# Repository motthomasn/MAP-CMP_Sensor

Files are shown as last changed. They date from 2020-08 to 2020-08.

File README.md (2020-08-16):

# MAP-CMP_Sensor
Small module combining a MAP sensor and engine phase sensor (camshaft posn) for internal combustion engine management

This module was built for my CBR250RRi project. The aim was to allow an aftermarket ECU to achieve 720deg synchronisation or engine phase detection without the use of a physical camshaft position sensor being installed on the engine. It has been designed for use on a port throttled engine and sample the pressure pulses from a single inlet port. 

The board uses an NXP pressure sensor to measure the pressure pulses. The pressure signal is passed to an LM397 comparator and compared to a reference voltage which can be adjusted via trim pot. The output signal from the comparator is normally high but when the pressure signal falls below the reference voltage, the output is pulled low. With the reference voltage set correctly, a reliable "cam position" signal can be achieved consisting of a single pulse per engine cycle.

Note: In a port throttled engine, the pressure signal may not be strong enough to produce a reliable signal throughout the engine speed/load range. In my application this is fine as the ECU I am working with (Life Racing F88R) allows the option to ignore the engine phase signal once 720deg synchronisation has been achieved. This means that the signal only has to be reliable during starting and idle.

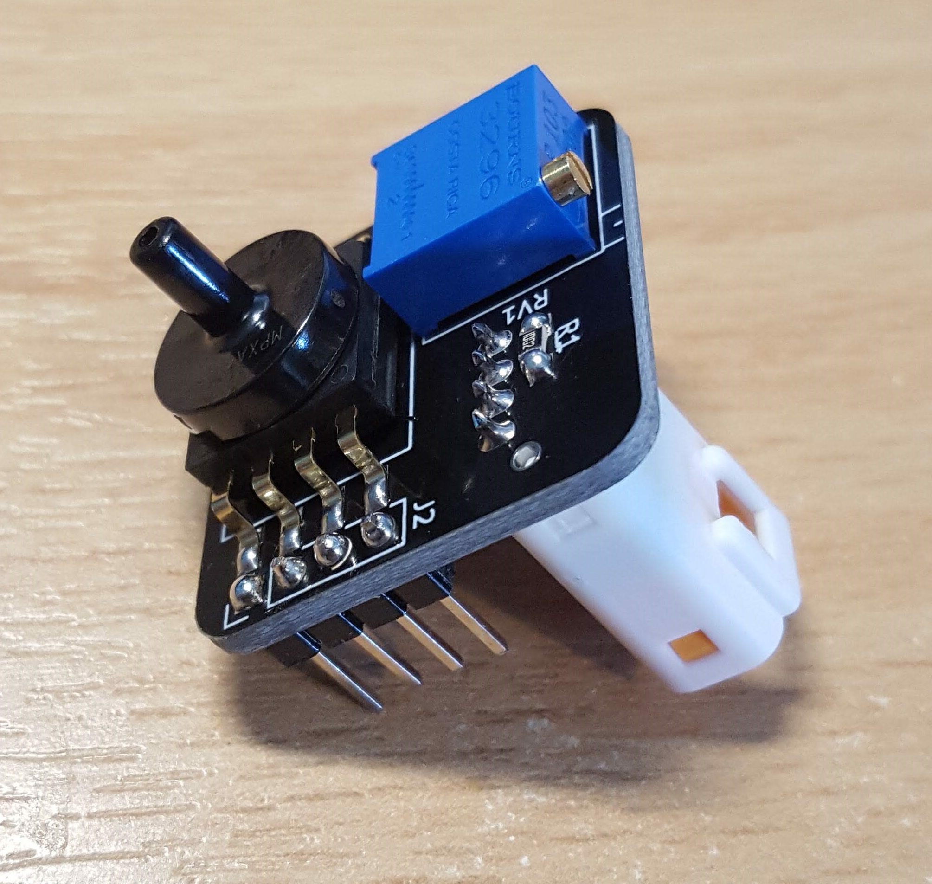
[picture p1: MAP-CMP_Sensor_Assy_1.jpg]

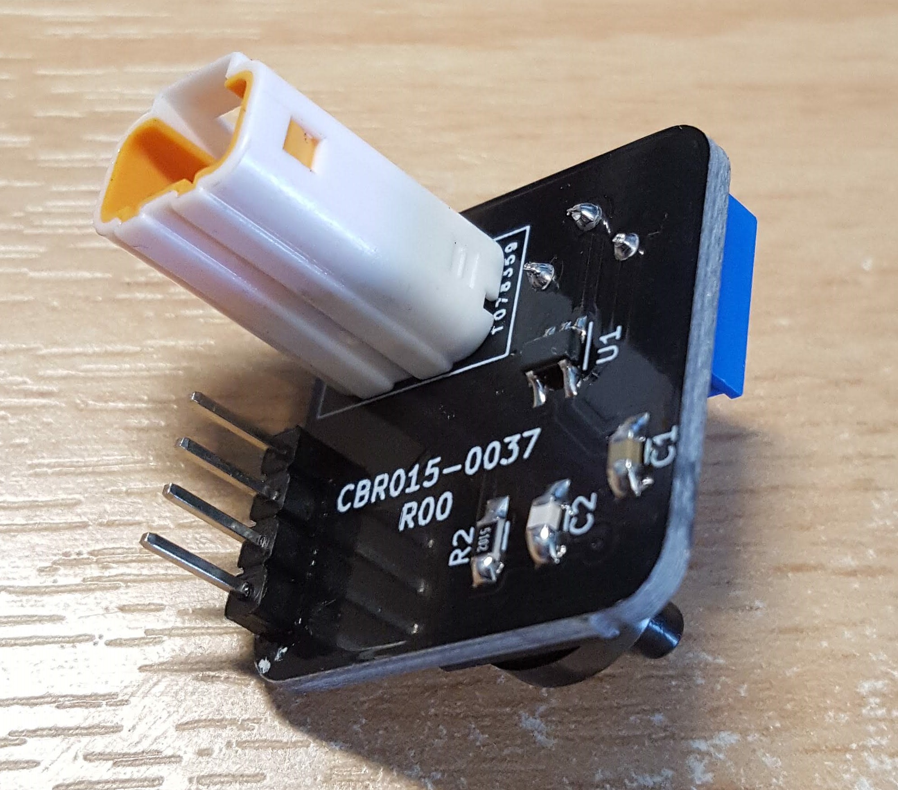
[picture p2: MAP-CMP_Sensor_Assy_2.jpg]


For further details on the CBR250RRi project, refer to the website https://www.cbr250rri.com/.

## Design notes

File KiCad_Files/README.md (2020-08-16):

This folder contains the KiCad files for the MAP-CMP module.

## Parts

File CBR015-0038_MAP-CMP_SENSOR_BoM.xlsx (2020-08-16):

Designation | Description | Value | Manufacturer | Part Number | Package | Supplier | Stock No. / Order Code | Notes | Datasheet
U1 | Comparator | 44μs, 30V | Texas Instruments | LM397MF/NOPB | SOT-23 | RS | 197-7286 |  | https://www.ti.com/lit/ds/symlink/lm397.pdf
U2 | Pressure Sensor | 15-115 kPa | NXP | MPXA6115AC6U |  | RS | 719-1134 |  | https://www.nxp.com/docs/en/data-sheet/MPXA6115A.pdf
RV1 | Trim Pot | 10K | Bourns | 3296P-1-103LF |  | RS | 521-9495 | May be replaced with fixed voltage divider in later revisions | https://www.bourns.com/pdfs/3296.pdf
J1 | Connector | 4 way male | JST | B04B-JWPF-SK-R |  | Farnell | 1324127 |  | http://www.farnell.com/datasheets/2082409.pdf
J2 | Debug Connector | 4 way male |  |  |  | RS |  | Only used to facilitate connection to oscilloscope for initial testing & debug. May be removed in later revisions
C1 | Pressure sensor power smooth cap | 100nF | AVX | 08055C104KAT2A | 0805 | RS | 464-6688
C2 | Pressure sensor output smooth cap | 47pF | KEMET | C0805C470J5GACTU | 0805 | RS | 264-4270
R1 | Comparator output pull-up resistor | 10K | TE Connectivity | CRG0805F10K | 0805 | RS | 223-0562
R2 | Pressure sensor output filter resistor | 51K | Vishay | CRCW080551K0FKEA | 0805 | RS | 679-1525

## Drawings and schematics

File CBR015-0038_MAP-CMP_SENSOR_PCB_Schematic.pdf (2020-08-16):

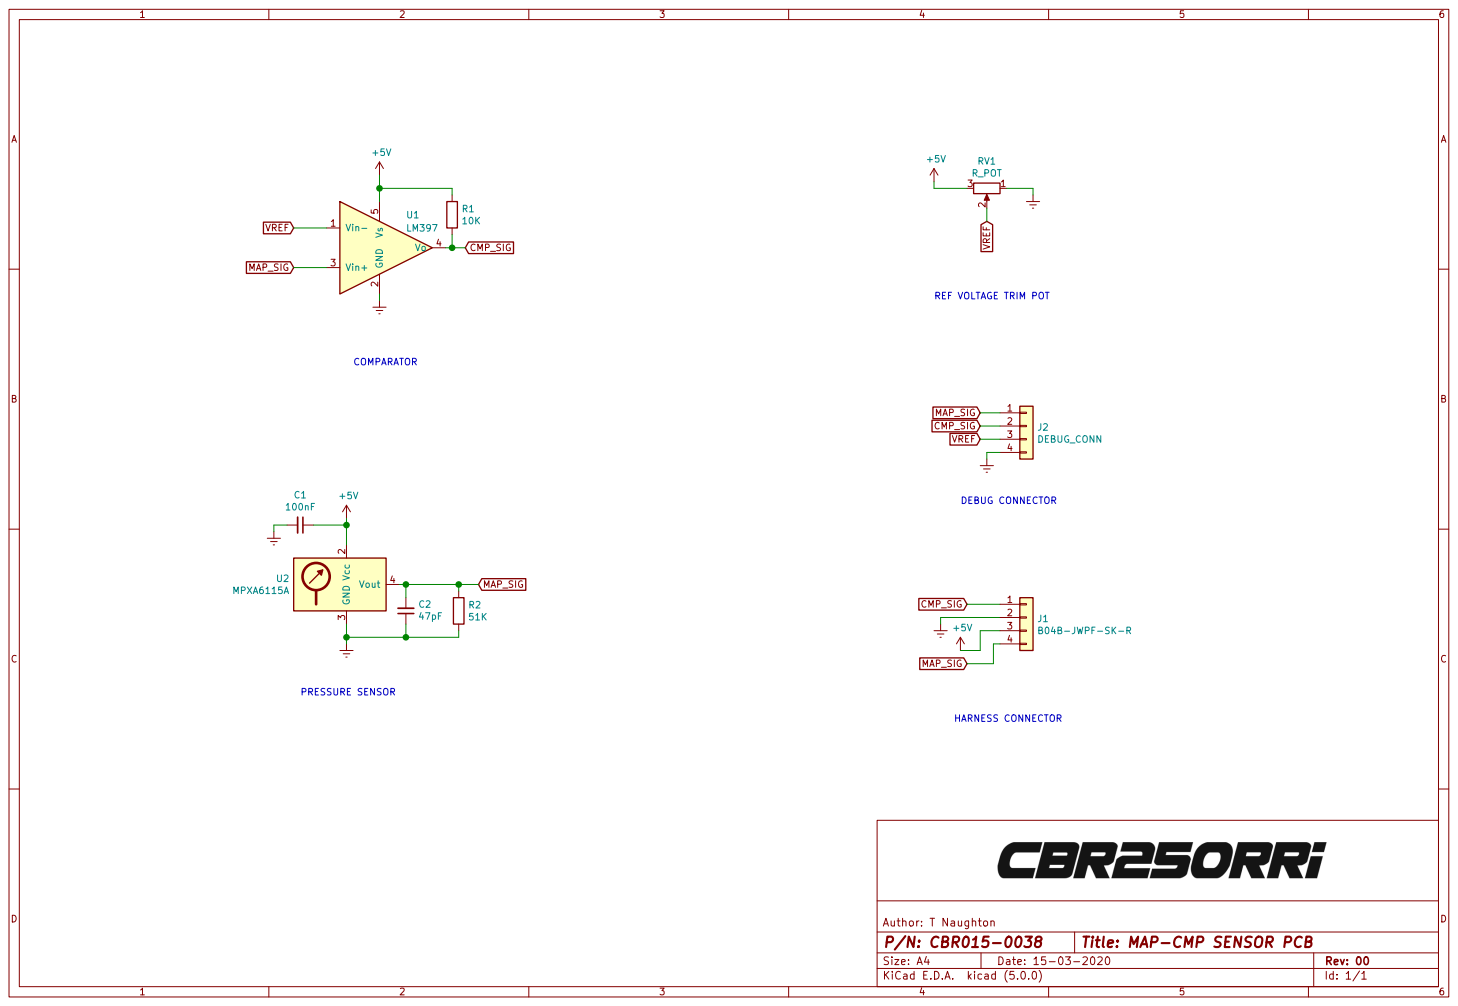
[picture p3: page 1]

+5V MAP_SIG
3 RV1 R_POT REF VOLTAGE TRIM POT VREF

Id: 1/1 Title: MAP-CMP SENSOR PCB

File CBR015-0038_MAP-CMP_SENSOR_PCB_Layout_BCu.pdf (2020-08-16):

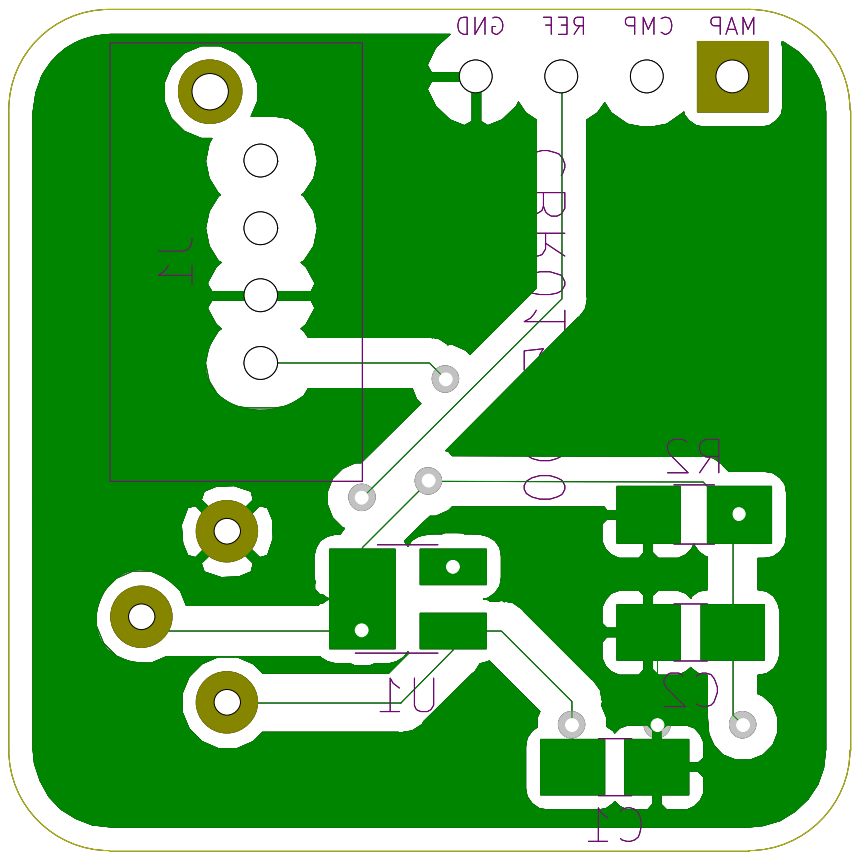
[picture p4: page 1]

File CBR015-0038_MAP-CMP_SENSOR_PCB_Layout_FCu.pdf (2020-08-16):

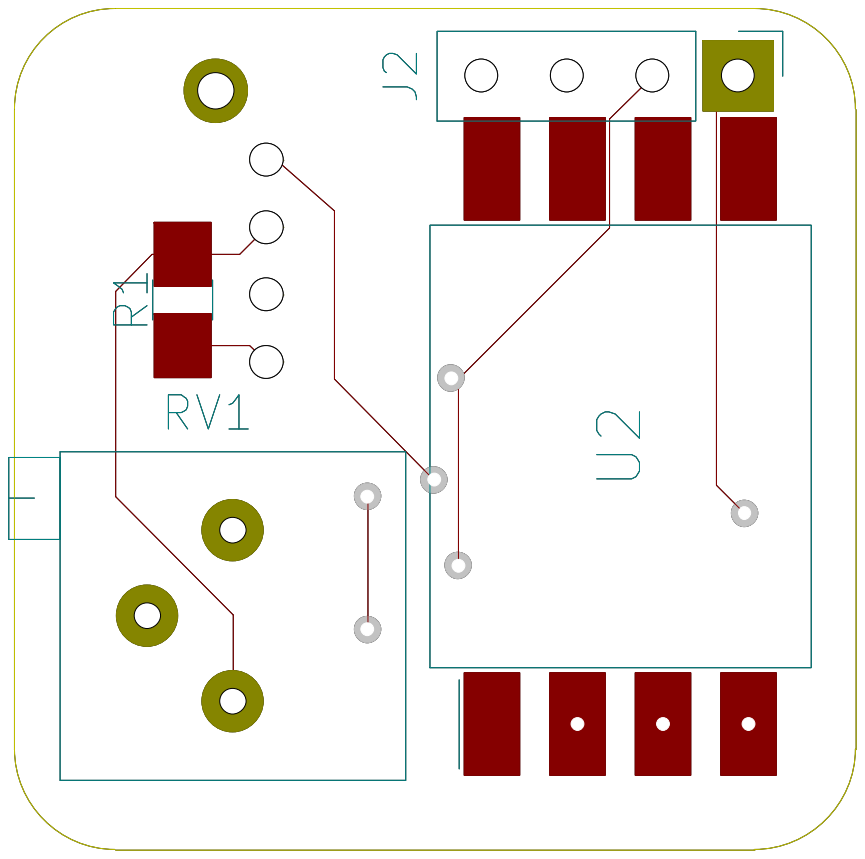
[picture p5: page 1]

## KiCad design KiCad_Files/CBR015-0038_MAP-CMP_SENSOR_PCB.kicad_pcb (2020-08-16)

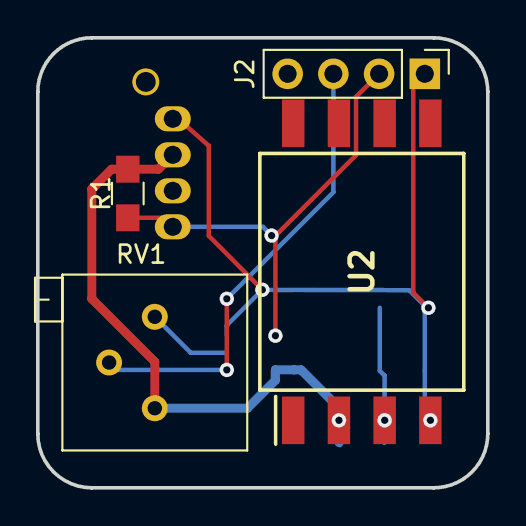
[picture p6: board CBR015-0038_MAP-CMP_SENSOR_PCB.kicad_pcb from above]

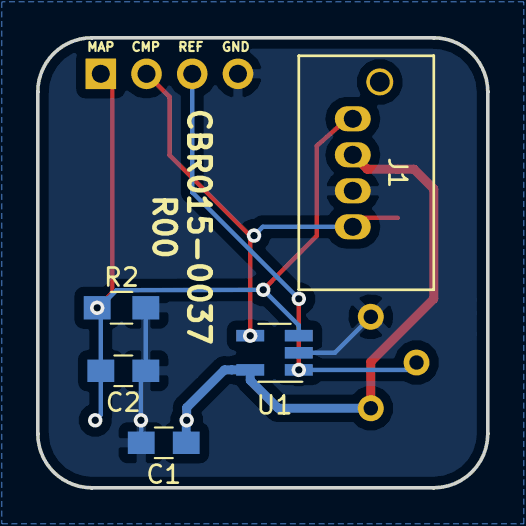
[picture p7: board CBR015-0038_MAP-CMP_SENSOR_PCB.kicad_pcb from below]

Board: 2 copper layers, 25.0 x 25.0 mm, 9 parts (5 on the bottom side), 5 nets.

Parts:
C1: 100nF; C_0805_HandSoldering
C2: 47pF; C_0805_HandSoldering
J1: B04B-JWPF-SK-R; JST_B04B-JWPF-SK-R
J2: DEBUG_CONN; Pin_Header_Straight_1x04_Pitch2.54mm
R1: 10K; R_0805_HandSoldering
R2: 51K; R_0805_HandSoldering
RV1: R_POT; Potentiometer_Bourns_3296P_Horizontal
U1: LM397; SOT-23-5_HandSoldering
U2: MPXA6115A; 98ASB17757C

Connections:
+5V: C1.1, J1.3, R1.1, RV1.3, U1.5, U2.2
CMP_SIG: J1.1, J2.2, R1.2, U1.4
Earth: C1.2, C2.1, J1.2, J2.4, R2.2, RV1.1, U1.2, U2.3
MAP_SIG: C2.2, J1.4, J2.1, R2.1, U1.3, U2.4
VREF: J2.3, RV1.2, U1.1
